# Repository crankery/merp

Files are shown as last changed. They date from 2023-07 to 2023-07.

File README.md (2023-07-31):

# Merp

Modular Eurorack Powerbus (Merp) is yet another power bus [KiCad](https://www.kicad.org/) project. Yes, we're truly breaking new ground here... This has never been done before. Ahem.

## Never been done before, eh?

OK. I may have started with [Eurorack Bus Board](https://github.com/butchwarns/Eurorack_Bus_Board) by Butch Warns. I was going to just order it but it was too wide for the cheap PCB fabrications. I think I iterated on his work enough to call this its own thing.

## Why Merp?

I think the only differentator with Merp from the other power bus PCBs is that Merp is designed to be ordered from one of the Chinese PCB fabs for their minimum price. [PCBWay](https://www.pcbway.com/) for example currently has 5 boards for $5 if they're under 100mm x 100mm which Merp qualifies for.

There are 6 power bus connectors per board. If you order 5 boards you can connect them all together and have 30 x 16 pin Doepfer sockets (I hope you have at least 104 hp rails if you're doing that) 

This board rquires +12V, -12V and +5V supplies. I'm using [Meanwell RT-65](https://www.meanwell.com/webapp/product/search.aspx?prod=RT-65) to power mine. The board has no +5V conversion and performs no power regulation. If none of your Eurorack modules use +5V you can get away without it.

Use a tested power supply. Before connecting any of your Eurorack modules, power up just the bus board. Ensure the LEDs are lit. Ensure that the correct voltages present.

# Renders

Here's some pictures of the board that KiCad generated.

## Front

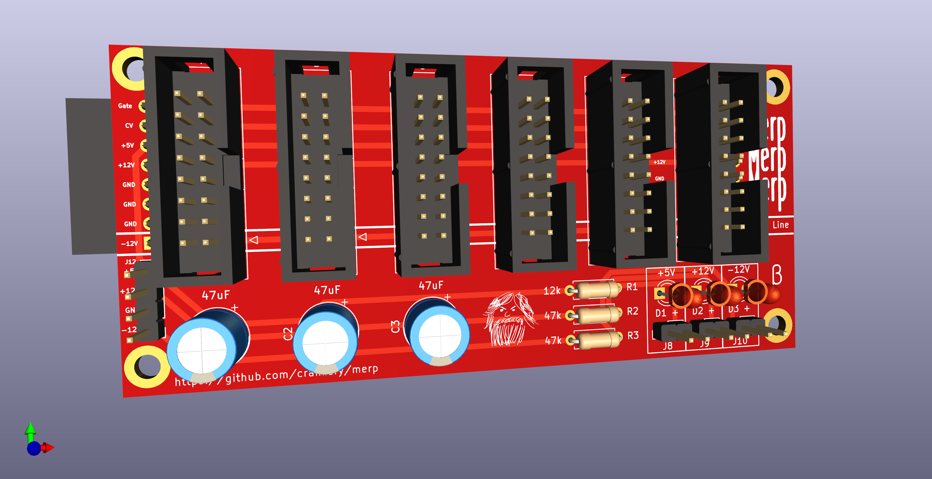
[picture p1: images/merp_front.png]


## Front Again

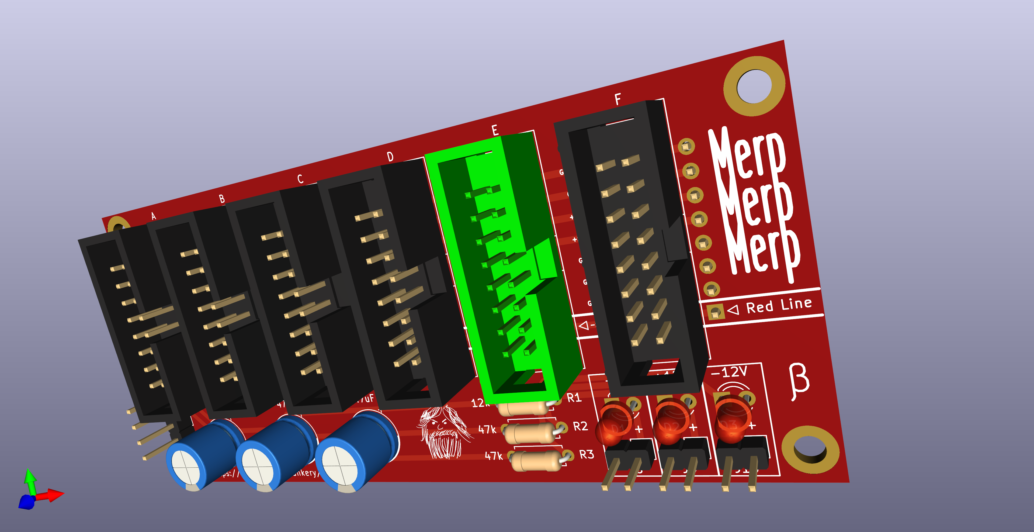
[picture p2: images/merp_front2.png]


The red line on Eurorack module power connectors are to be installed towards the bottom of the board as indicated although this should be enforced by the IDC connector notches.

## Back

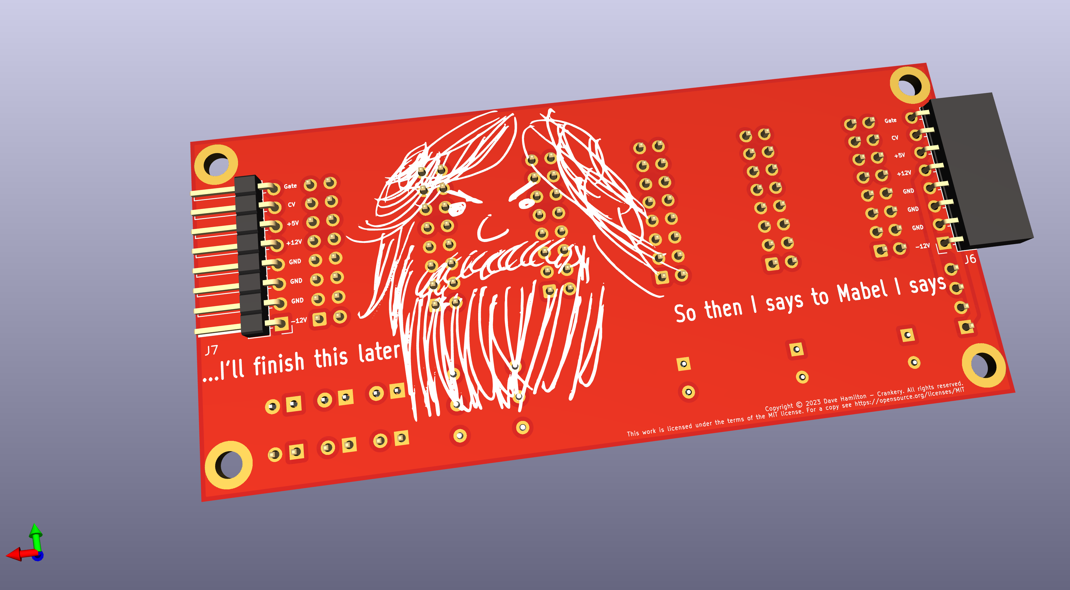
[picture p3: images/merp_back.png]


# Notes

- The resistor values are just a starting point. I find the +12 LED to be too bright and the +5 to be too dim with these values. They're simply there to make the power indicator LEDs a bit dimmer.
- The LEDs and the pin headers below them are the same thing. If you're connecting an LED via a header, ensure the positive leg connects to the + pin (note the pad shapes are opposite for the -12V led, the cathode is on the same side when mounted though.)
- If you don't want to use the LEDs you can leave the resistors, LEDs and associated headers unpopulated. They are not required for operation of the power bus.
- The interconnect header & socket are shown to be mounted on the back on the boards. The boards are intended to be installed in your Eurorack case on standoffs. The board should be about 5mm bigger in that dimension for this reason (it might make sense to make the whole board twice as tall to allow for staggering of the connectors as they're pretty tight)
- If you don't want to connect a module to the left or right, leave the interconnect header or socket unpopulated.
- There's an additional power header on the left side of the board. This header is entirely optional. A future revision will likely make this a screw terminal instead of a pin header.
- You can probably only populate the filter capacitors on one of your boards. Or none of them... They're optional.
- All signals are passed through all interconnected power bus modules.
- The Gate and CV lines of the Doepfer bus are connected, inclusive of module interconnects.
- The mounting holes are suitable for M3 bolts & standoffs.

# BOM

All parts are THT.

|Designator|Package|Quantity|Designation|
|-|-|-|-|
|R1|Axial Resistor 1/4W |1|12k*|
|R2,R3|Axial Resistor 1/4W|2|47k*|
|J1,J2,J3,J4,J5,J10,J11|16 Pin Eurorack Power Male|6|A,B,C,D,E,F|
|C3,C2,C1|Electrolytic Capactior|3|47uF|
|D1,D2,D3|3mm LED|1|+5V,+12V,-12V|
|J8,J9,J10|Pin Header 1x2 2.54mm Pitch Vertical|3|+5V,+12V,-12V|
|J12|Pin Connector 1x4 2.54mm Pitch|1||
|J6|Pin Socket 1x8 2.54mm Pitch Horizontal|1|IO1|
|J7|Pin Header 1x8 2.54mm Pitch Horizontal|1|IO2|

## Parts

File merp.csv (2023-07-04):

Id | Designator | Package | Quantity | Designation | Supplier and ref
1 | R2,R3 | R_Axial_DIN0207_L6.3mm_D2.5mm_P7.62mm_Horizontal | 2 | 47k
2 | J2 | IDC-Header_2x08_P2.54mm_Vertical | 1 | B
3 | C3,C2,C1 | CP_Radial_D8.0mm_P3.50mm | 3 | 47uF
4 | J10 | PinHeader_1x02_P2.54mm_Vertical | 1 | -12V
5 | J1 | IDC-Header_2x08_P2.54mm_Vertical | 1 | A
6 | J9 | PinHeader_1x02_P2.54mm_Vertical | 1 | +12V
7 | H3,H2,H1,H4 | MountingHole_3.2mm_M3_DIN965_Pad | 4 | GND
8 | J4 | IDC-Header_2x08_P2.54mm_Vertical | 1 | D
9 | J3 | IDC-Header_2x08_P2.54mm_Vertical | 1 | C
10 | D3 | LED_D3.0mm | 1 | -12V
11 | D1 | LED_D3.0mm | 1 | +5V
12 | J8 | PinHeader_1x02_P2.54mm_Vertical | 1 | +5V
13 | D2 | LED_D3.0mm | 1 | +12V
14 | R1 | R_Axial_DIN0207_L6.3mm_D2.5mm_P7.62mm_Horizontal | 1 | 12k
15 | J5 | IDC-Header_2x08_P2.54mm_Vertical | 1 | E
16 | J11 | IDC-Header_2x08_P2.54mm_Vertical | 1 | F
17 | J12 | PinHeader_1x04_P2.54mm_Vertical | 1 | Conn_01x04_Male
18 | J6 | PinSocket_1x08_P2.54mm_Horizontal | 1 | IO1
19 | J7 | PinHeader_1x08_P2.54mm_Horizontal | 1 | IO2

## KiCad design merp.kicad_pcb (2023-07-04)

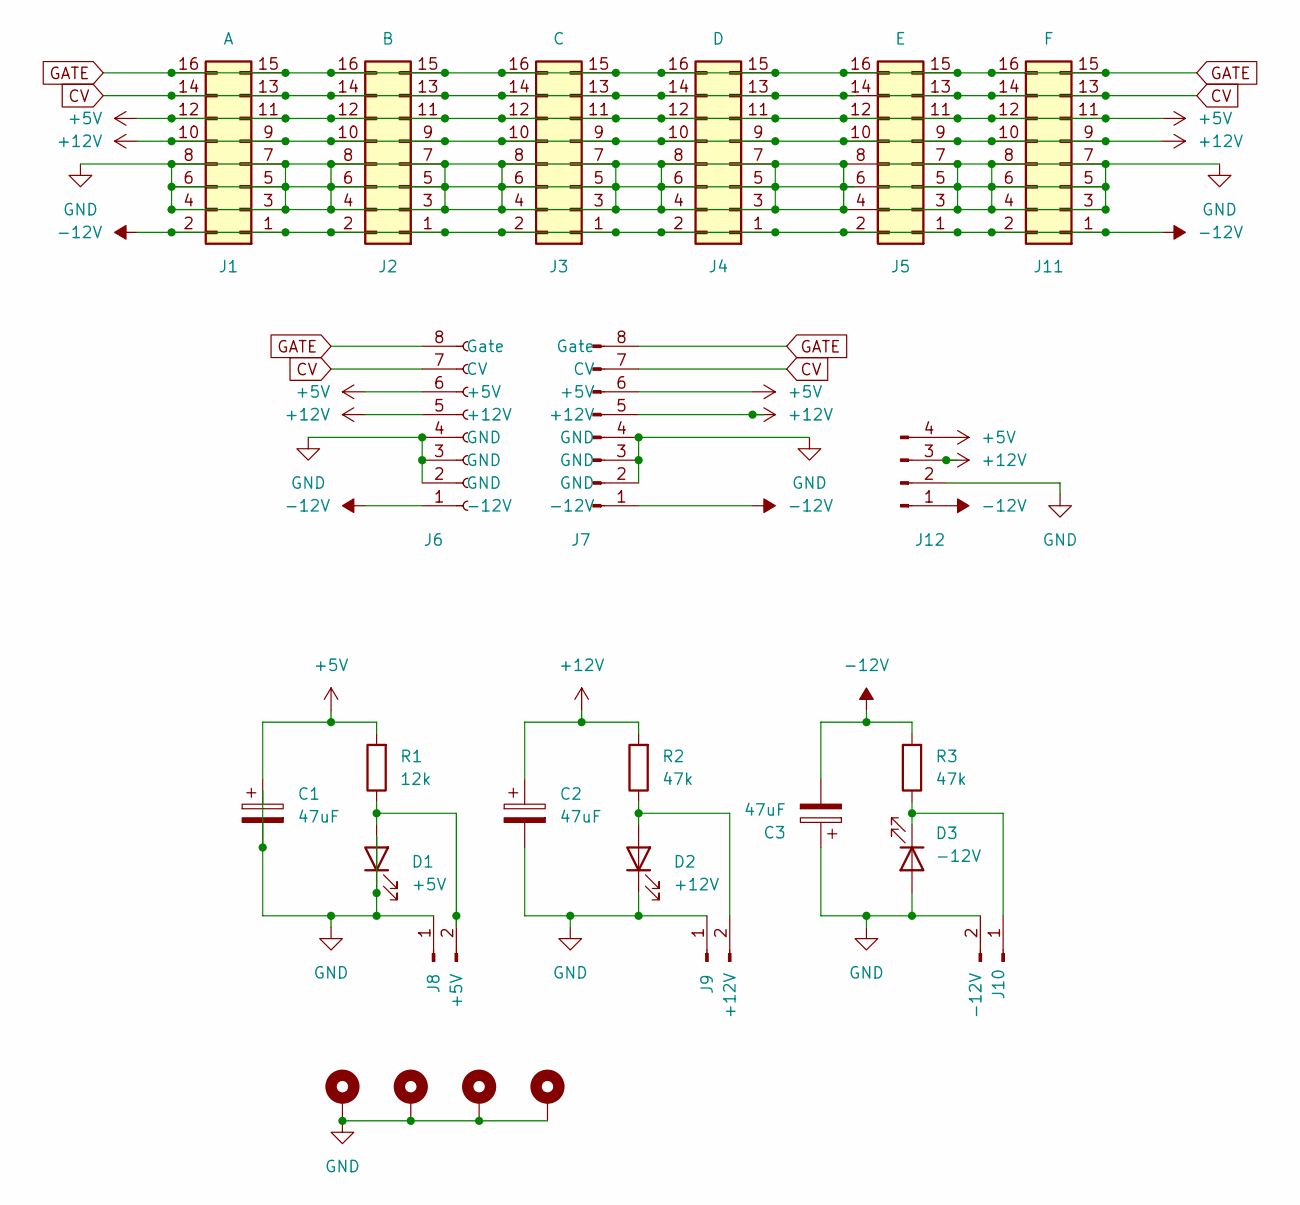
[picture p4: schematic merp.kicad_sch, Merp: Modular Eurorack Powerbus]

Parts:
C1, C2, C3: 47uF; CP_Radial_D8.0mm_P3.50mm
D1: +5V; LED_D3.0mm
D2: +12V; LED_D3.0mm
D3: -12V; LED_D3.0mm
H1, H2, H3, H4: GND; MountingHole_3.2mm_M3_DIN965_Pad
J1: A; IDC-Header_2x08_P2.54mm_Vertical
J2: B; IDC-Header_2x08_P2.54mm_Vertical
J3: C; IDC-Header_2x08_P2.54mm_Vertical
J4: D; IDC-Header_2x08_P2.54mm_Vertical
J5: E; IDC-Header_2x08_P2.54mm_Vertical
J6: IO1; PinSocket_1x08_P2.54mm_Horizontal
J7: IO2; PinHeader_1x08_P2.54mm_Horizontal
J8: +5V; PinHeader_1x02_P2.54mm_Vertical
J9: +12V; PinHeader_1x02_P2.54mm_Vertical
J10: -12V; PinHeader_1x02_P2.54mm_Vertical
J11: F; IDC-Header_2x08_P2.54mm_Vertical
J12: Conn_01x04_Male; PinHeader_1x04_P2.54mm_Horizontal
R1: 12k; R_Axial_DIN0207_L6.3mm_D2.5mm_P7.62mm_Horizontal
R2, R3: 47k; R_Axial_DIN0207_L6.3mm_D2.5mm_P7.62mm_Horizontal

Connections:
+5V: C1.1, J1.11, J1.12, J2.11, J2.12, J3.11, J3.12, J4.11, J4.12, J5.11, J5.12, J6.6 (+5V), J7.6 (+5V), J11.11, J11.12, J12.4, R1.2
+12V: C2.1, J1.9, J1.10, J2.9, J2.10, J3.9, J3.10, J4.9, J4.10, J5.9, J5.10, J6.5 (+12V), J7.5 (+12V), J11.9, J11.10, J12.3, R2.2
-12V: C3.2, J1.1, J1.2, J2.1, J2.2, J3.1, J3.2, J4.1, J4.2, J5.1, J5.2, J6.1 (-12V), J7.1 (-12V), J11.1, J11.2, J12.1, R3.2
CV: J1.13, J1.14, J2.13, J2.14, J3.13, J3.14, J4.13, J4.14, J5.13, J5.14, J6.7 (CV), J7.7 (CV), J11.13, J11.14
GATE: J1.15, J1.16, J2.15, J2.16, J3.15, J3.16, J4.15, J4.16, J5.15, J5.16, J6.8 (Gate), J7.8 (Gate), J11.15, J11.16
GND: C1.2, C2.2, C3.1, D1.1 (K), D2.1 (K), D3.2 (A), H1.1, H2.1, H3.1, H4.1, J1.3, J1.4, J1.5, J1.6, J1.7, J1.8, J2.3, J2.4, J2.5, J2.6, J2.7, J2.8, J3.3, J3.4, J3.5, J3.6, J3.7, J3.8, J4.3, J4.4, J4.5, J4.6, J4.7, J4.8, J5.3, J5.4, J5.5, J5.6, J5.7, J5.8, J6.2 (GND), J6.3 (GND), J6.4 (GND), J7.2 (GND), J7.3 (GND), J7.4 (GND), J8.1, J9.1, J10.2, J11.3, J11.4, J11.5, J11.6, J11.7, J11.8, J12.2
unnamed: D1.2 (A), J8.2, R1.1
unnamed: D2.2 (A), J9.2, R2.1
unnamed: D3.1 (K), J10.1, R3.1

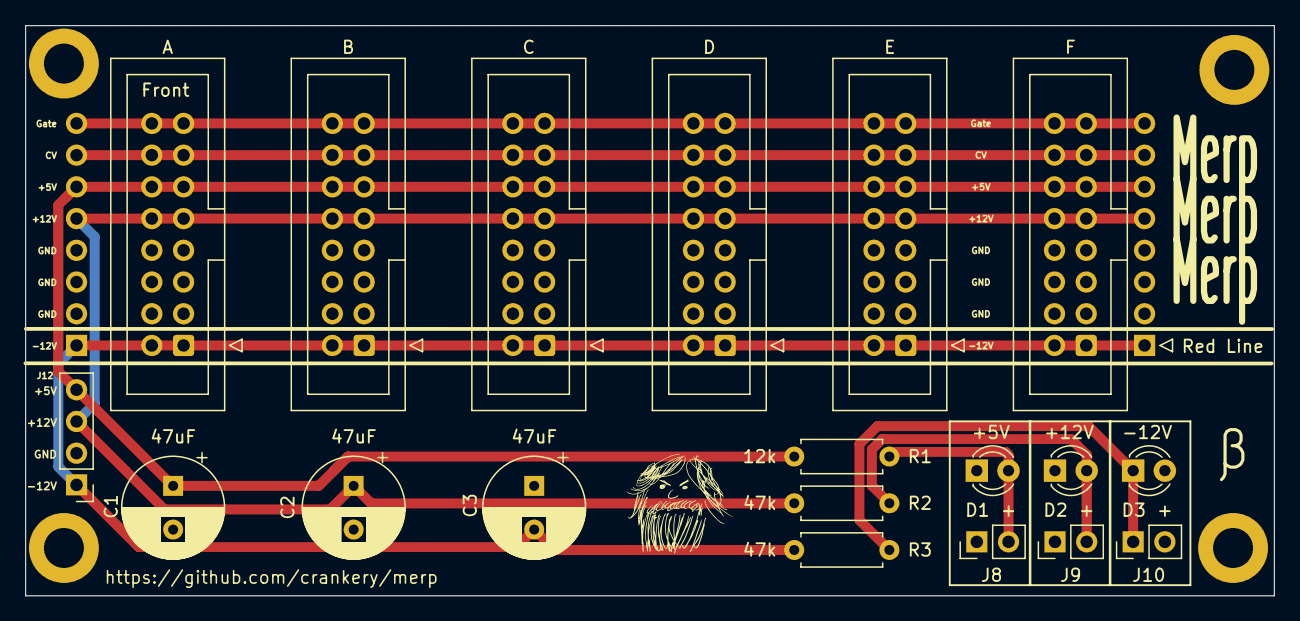
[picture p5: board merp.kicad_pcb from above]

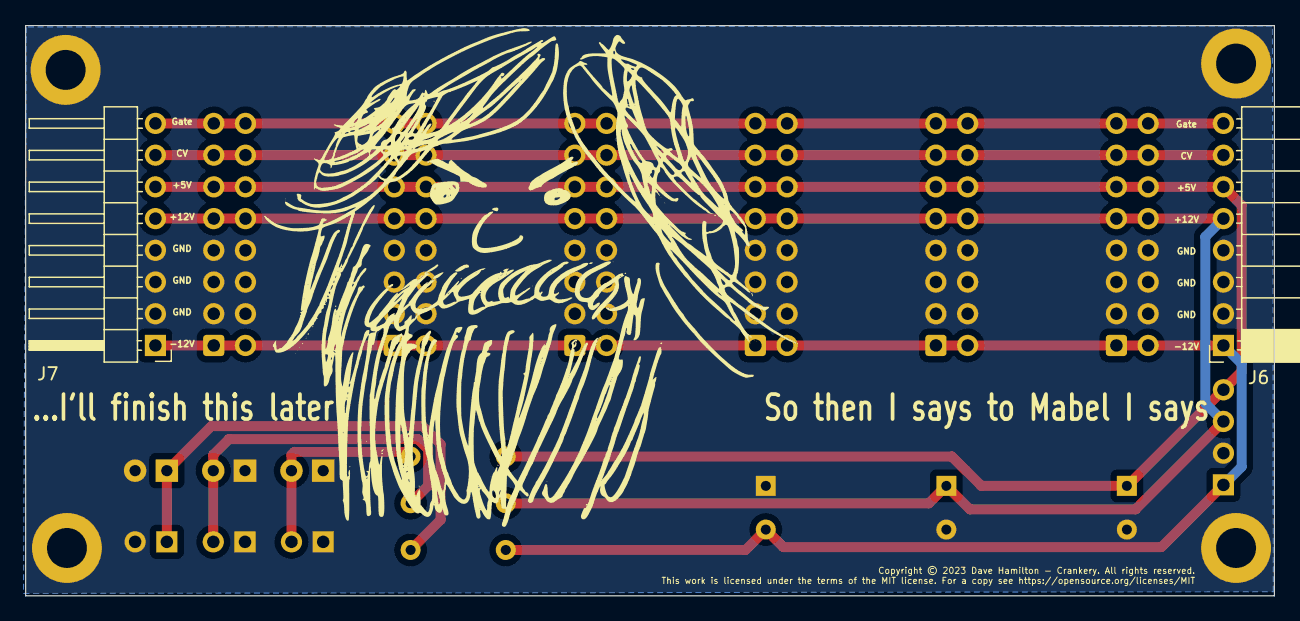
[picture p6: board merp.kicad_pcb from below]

Board: 2 copper layers, 100.0 x 45.7 mm, 26 parts (2 on the bottom side), 9 nets.

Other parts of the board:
G1: LOGO; crankery_small

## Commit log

2023-07-04 add project to source control
    [merp.kicad_pcb, merp.kicad_sch]
2023-07-04 add gerbers
    [merp-B_Cu.gbr, merp-B_Mask.gbr, merp-B_Silkscreen.gbr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]
2023-07-04 add BOM
    [merp.csv]
2023-07-04 fix url on board
    upgrade to kicad 7
    [merp.kicad_pcb, merp.kicad_sch]
2023-07-04 update gerbers and front images
    [merp-B_Cu.gbr, merp-B_Mask.gbr, merp-B_Silkscreen.gbr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]
2023-07-04 bigger sample images
2023-07-04 more churn
    [merp.kicad_pcb]
2023-07-28 remove pessimistic note about mounting holes. they're fine.

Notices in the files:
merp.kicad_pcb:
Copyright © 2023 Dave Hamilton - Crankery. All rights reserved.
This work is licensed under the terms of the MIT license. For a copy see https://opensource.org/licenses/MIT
